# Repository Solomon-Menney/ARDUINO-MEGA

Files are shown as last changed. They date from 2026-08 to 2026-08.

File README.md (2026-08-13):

## 📌 Project Overview

The **Custom Arduino Mega** is an open-source hardware project developed as a custom implementation of the Arduino Mega platform.

The board is suitable for:

* Embedded systems development
* Robotics projects
* Automation and control systems
* IoT applications
* Sensor interfacing
* Motor control
* Electronics prototyping
* Academic and engineering projects

---

## ✨ Features

* ATmega2560 microcontroller
* Arduino Mega-compatible architecture
* Digital I/O pins
* Analog input pins
* PWM outputs
* UART serial communication
* SPI communication
* I²C communication
* USB programming/communication interface
* External power input
* On-board voltage regulation
* Reset circuit
* ICSP programming interface
* Power and status indicators
* Standard Arduino-style headers

---

## 🔧 Main Specifications

| Parameter | Specification  |
| --- | --- |
| Microcontroller | ATmega2560 |
| Architecture | 8-bit AVR |
| Operating Voltage | 5 V |
| Digital I/O | 54 |
| PWM Outputs | 15 |
| Analog Inputs | 16 |
| UART Ports | 4 |
| Communication | UART, SPI, I²C |
| Clock Frequency | 16 MHz |
| Programming | USB / ICSP |
| PCB Design Software | KiCad |
| Board Type | Custom PCB |

---

## 🧠 Microcontroller

The main controller used on the board is the **ATmega2560**.

The microcontroller provides a large number of digital and analog I/O pins, making the board suitable for projects that require more pins than a standard Arduino Uno.

### ATmega2560 Functions

* Digital input/output
* Analog-to-digital conversion
* PWM generation
* Hardware timers
* UART communication
* SPI communication
* I²C communication
* External interrupts
* Flash, SRAM and EEPROM memory

---

## 🔌 Communication Interfaces

The board supports several communication protocols.

### UART

The ATmega2560 provides four hardware serial interfaces:

* Serial0
* Serial1
* Serial2
* Serial3

These can be used to communicate with:

* GPS modules
* GSM modules
* Bluetooth modules
* Other microcontrollers
* Computers

### I²C

I²C can be used to connect devices such as:

* Sensors
* LCD displays
* RTC modules
* EEPROMs
* I/O expanders

### SPI

SPI can be used for high-speed communication with:

* SD cards
* Displays
* Sensors
* Flash memory
* Other SPI devices

---

## ⚡ Power Supply

The board contains a dedicated power section for supplying the required voltage to the microcontroller and other circuits.

Possible power sources include:

* USB
* External DC input

The power section includes:

* Voltage regulation
* Power filtering
* Decoupling capacitors
* Reverse-polarity protection *(if implemented)*
* Power indicator LED

> **Note:** Verify the exact input-voltage range of your implemented power circuit before connecting an external supply.

---

## 🔄 Reset Circuit

A reset circuit is included to allow the ATmega2560 to restart and enter the bootloader/programming process.

The reset circuit consists of components such as:

* Reset push button
* Pull-up resistor
* Reset capacitor *(depending on the design)*

---

## 💻 Programming

The board can be programmed using the Arduino IDE or another compatible AVR development environment.

### Arduino IDE

1. Install the Arduino IDE.
2. Connect the board to a computer through USB.
3. Select the appropriate board configuration.
4. Select the correct COM port.
5. Upload your Arduino program.

For a Mega-compatible configuration, select:

**Tools → Board → Arduino Mega or Mega 2560**

Then select the appropriate processor option for your hardware.

## 🖥️ PCB Design

The PCB was designed using **KiCad**.

The project includes the following design files:

```text
Custom-Arduino-Mega/
│
├── README.md
│
├── Schematic/
│   └── Arduino_Mega.kicad_sch
│
├── PCB/
│   └── Arduino_Mega.kicad_pcb
│
├── Gerber/
│   └── Manufacturing_Files/
│
├── 3D/
│   └── PCB_3D_View/
│
└── Documentation/
    ├── Pinout/
    └── Images/
```

---

## 📐 Design Files

The repository contains:

* KiCad schematic
* KiCad PCB layout
* Gerber files
* Drill files
* Bill of Materials (BOM)
* Component datasheets
* Firmware/test programs
* PCB renders
* Project documentation

---

## 🧾 Bill of Materials

| Component | Description | Quantity |
| --- | --- | ---: |
| ATmega2560 | Main microcontroller | 1 |
| USB Interface | USB communication/programming | 1 |
| Voltage Regulator  | 5 V regulation | 1 |
| Crystal/Oscillator | 16 MHz clock | 1 |
| Capacitors | Power/decoupling | Several |
| Resistors | Pull-up/current limiting | Several |
| LEDs | Power/status indicators | Several |
| Push Button | Reset | 1 |
| Pin Headers | I/O connections | Several |
| Diodes | Protection | As required |

> The exact component values and part numbers are provided in the project schematic and BOM.

---

## 📷 Project Images

Add your project images here.

### Schematic

Schematic

### PCB Layout

PCB Layout

### 3D PCB View

3D PCB

This custom Arduino Mega board can be used in:

* Industrial automation
* Robotics
* Smart home systems
* IoT systems
* Solar energy systems
* Motor control
* Sensor networks
* Data acquisition
* Embedded control systems
* Engineering research and education

---

## 🛠️ Tools Used

### Hardware Design

* KiCad
* ATmega2560 datasheet
* AVR documentation

### Software

* Arduino IDE
* AVR toolchain

### Manufacturing

* PCB fabrication service
* Soldering and assembly tools

---

Documentation

Important documents are included in the `Documentation` directory.

These may include:

* Circuit schematic
* PCB layout
* Pinout diagram
* Datasheets
* BOM
* Design calculations
* Assembly information
* Testing results

---

Recommended Tests

* [ ] Visual inspection
* [ ] Check for PCB shorts
* [ ] Verify power input
* [ ] Verify regulated voltage
* [ ] Test reset circuit
* [ ] Test USB communication
* [ ] Test microcontroller programming
* [ ] Test digital I/O
* [ ] Test analog inputs
* [ ] Test UART
* [ ] Test I²C
* [ ] Test SPI

---

## 📈 Future Improvements

Possible future improvements include:

* Improved power protection
* USB-C connector
* Additional power monitoring
* Battery input
* Reverse-polarity protection
* ESD protection
* Improved PCB layout
* Additional status indicators
* More expansion connectors
* Improved thermal management

---

 Author
SOLOMON MENNEY
Electrical/Electronic Engineering Student
Accra Technical University

**Built with KiCad, AVR technology, and a passion for embedded systems.**

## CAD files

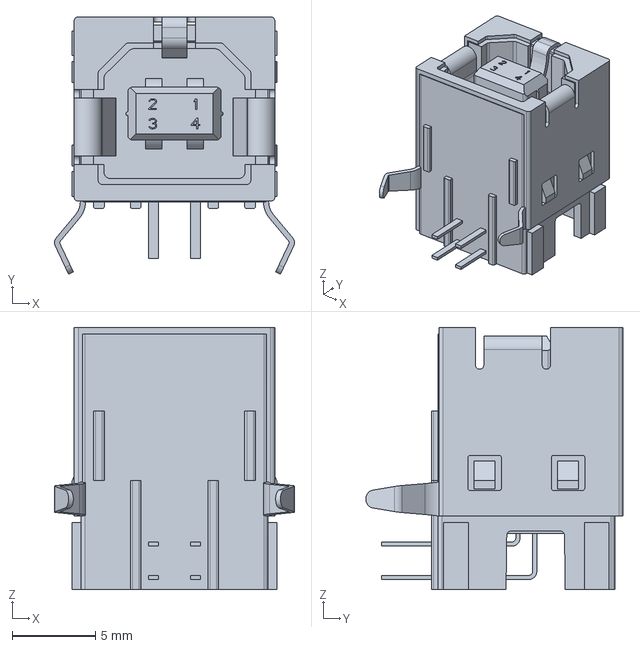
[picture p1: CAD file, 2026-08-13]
100623.stp
14.4 x 15.4 x 15.7 mm

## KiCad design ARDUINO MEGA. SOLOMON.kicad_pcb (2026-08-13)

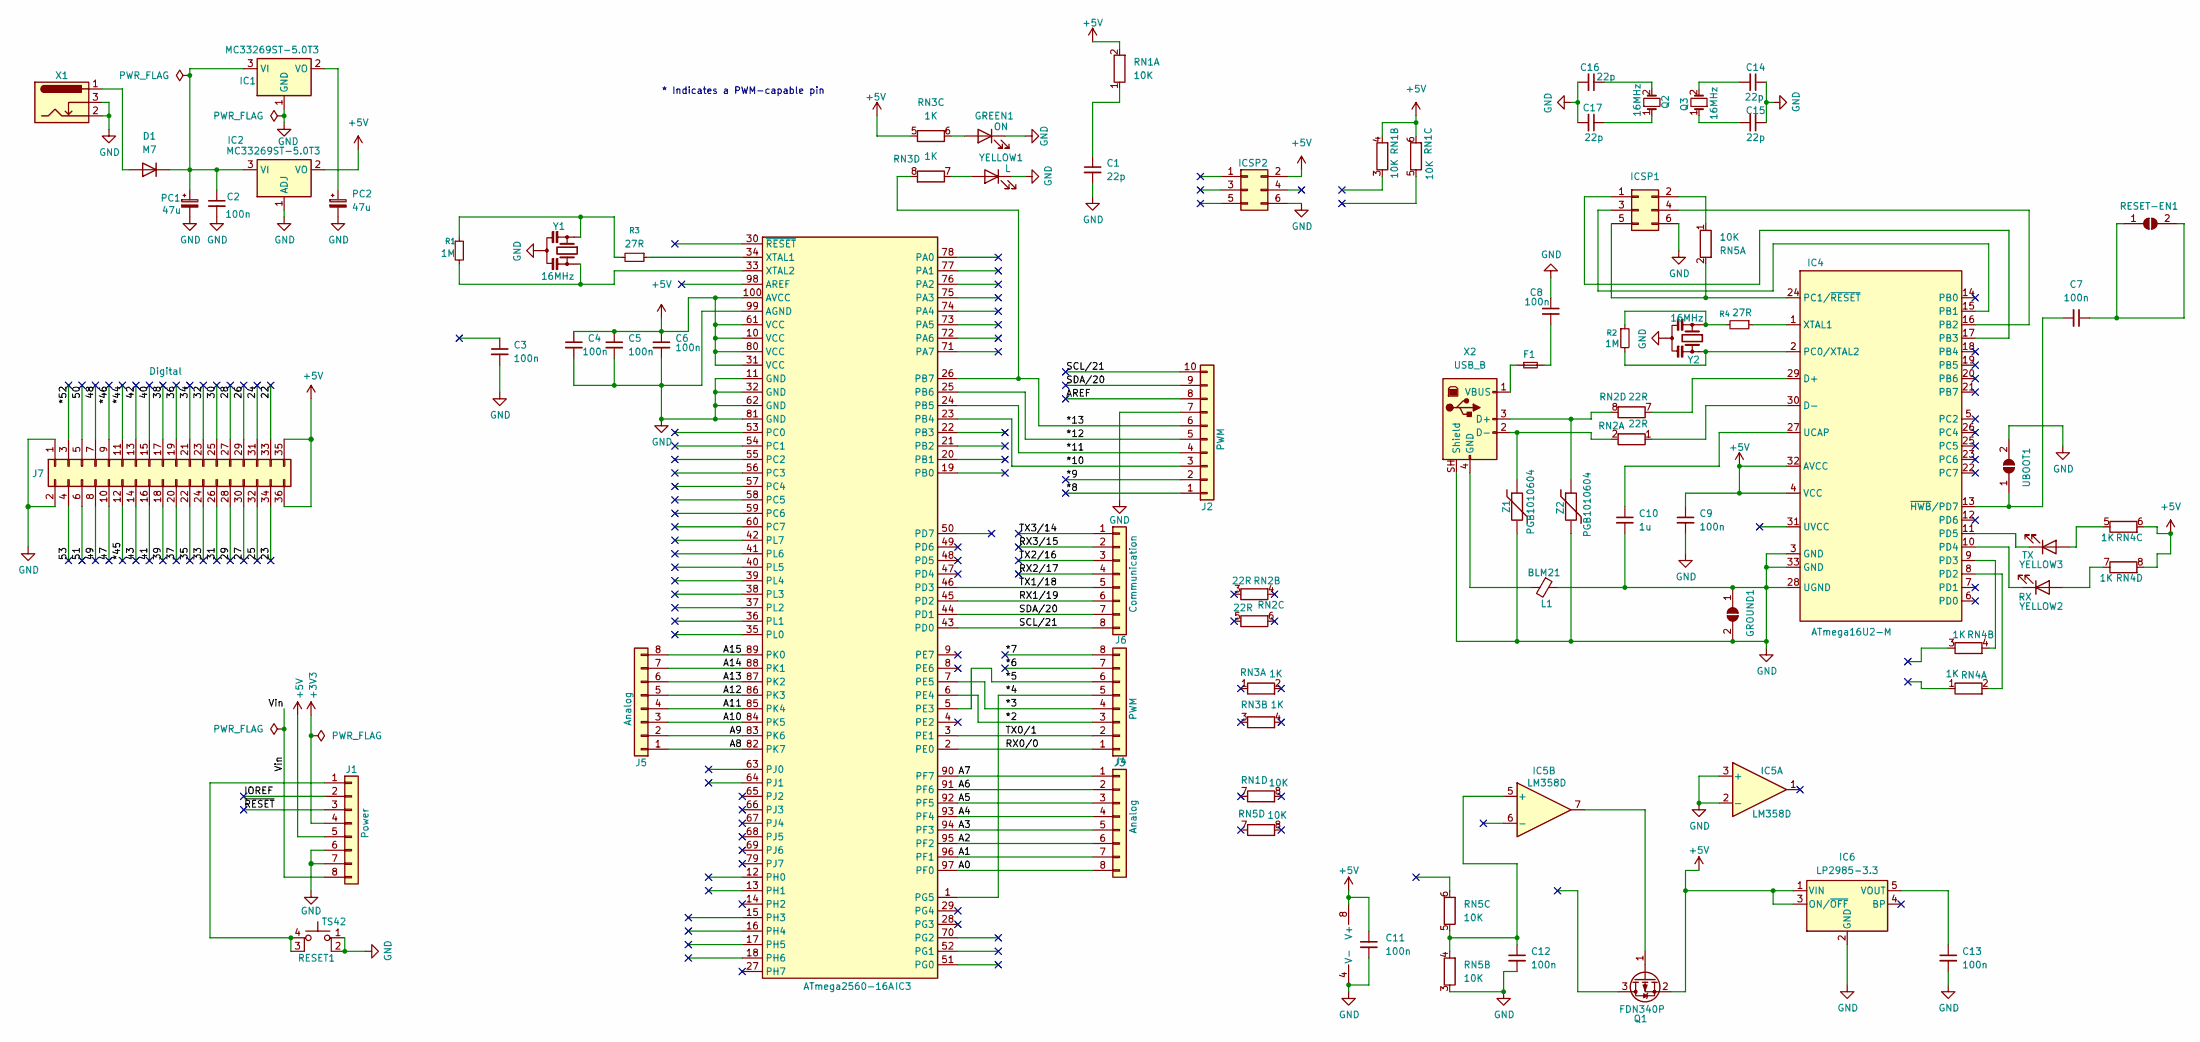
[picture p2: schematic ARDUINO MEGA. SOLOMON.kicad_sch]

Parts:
C1, C14, C15, C16, C17: 22p; C_0805_2012Metric
C2, C3, C4, C5, C6, C7, C8, C9, C11, C12, C13: 100n; C_0805_2012Metric
C10: 1u; C_0805_2012Metric
D1: M7; D_SMA
F1: 500mA; Fuse_1812_4532Metric
GREEN1: ON; LED_0805_2012Metric
GROUND1: SolderJumper_2_Open; SolderJumper-2_P1.3mm_Bridged_Pad1.0x1.5mm
IC1, IC2: MC33269ST-5.0T3; SOT-223-3_TabPin2
IC3: ATmega2560-16A; TQFP-100_14x14mm_P0.5mm
IC4: ATmega16U2-M; QFN-32-1EP_5x5mm_P0.5mm_EP3.1x3.1mm
IC5: LM358D; SOIC-8_3.9x4.9mm_P1.27mm
IC6: LP2985-3.3; SOT-23-5
ICSP1, ICSP2: Conn_02x03_Odd_Even; PinHeader_2x03_P2.54mm_Vertical
J1: Power; PinSocket_1x08_P2.54mm_Vertical
J2: PWM; PinSocket_1x10_P2.54mm_Vertical
J3, J5: Analog; PinSocket_1x08_P2.54mm_Vertical
J4: PWM; PinSocket_1x08_P2.54mm_Vertical
J6: Communication; PinSocket_1x08_P2.54mm_Vertical
J7: Digital; PinSocket_2x18_P2.54mm_Vertical
L1: BLM21; L_0805_2012Metric
PC1, PC2: 47u; CP_Elec_6.3x5.4
Q1: FDN340P; SOT-23
Q2, Q3: 16MHz; Crystal_SMD_5032-2Pin_5.0x3.2mm
R1, R2: 1M; R_0805_2012Metric
R3, R4: 27R; R_0805_2012Metric
RESET1: TS42; SW_SPST_PTS645Sx43SMTR92
RESET-EN1: SolderJumper_2_Open; SolderJumper-2_P1.3mm_Bridged_Pad1.0x1.5mm
RN1, RN5: 10K; R_Array_Convex_4x0603
RN2: 22R; R_Array_Convex_4x0603
RN3, RN4: 1K; R_Array_Convex_4x0603
UBOOT1: SolderJumper_2_Open; SolderJumper-2_P1.3mm_Bridged_Pad1.0x1.5mm
X1: Barrel_Jack_Switch; BarrelJack_Horizontal
X2: USB_B; USB_B_OST_USB-B1HSxx_Horizontal
Y1: 16MHz; Crystal_SMD_HC49-SD
Y2: 16MHz; Resonator_SMD_Murata_CSTxExxV-3Pin_3.0x1.1mm
YELLOW1: L; LED_0805_2012Metric
YELLOW2: RX; LED_0805_2012Metric
YELLOW3: TX; LED_0805_2012Metric
Z1, Z2: PGB1010604; R_0603_1608Metric

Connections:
+3V3: J1.4
+5V: C4.1, C5.1, C6.1, C9.1, C11.1, IC2.2 (VO), IC3.10 (VCC), IC3.31 (VCC), IC3.61 (VCC), IC3.80 (VCC), IC3.100 (AVCC), IC4.4 (VCC), IC4.32 (AVCC), IC5.8 (V+), IC6.1 (VIN), IC6.3 (ON/~OFF), ICSP2.2, J1.5, J7.35, J7.36, Q1.2 (S), RN1.2 (R1.2), RN1.4 (R2.2), RN1.6 (R3.2), RN3.5 (R3.1), RN4.6 (R3.2), RN4.8 (R4.2)
/22: J7.33
/23: J7.34
/24: J7.31
/25: J7.32
/26: J7.29
/27: J7.30
/28: J7.27
/29: J7.28
/30: J7.25
/31: J7.26
/32: J7.23
/33: J7.24
/34: J7.21
/35: J7.22
/36: J7.19
/37: J7.20
/38: J7.17
/39: J7.18
/40: J7.15
/41: J7.16
/42: J7.13
/43: J7.14
/47: J7.10
/48: J7.7
/49: J7.8
/50: J7.5
/51: J7.6
/53: J7.4
/*2: IC3.6 (PE4), J4.3
/*3: IC3.7 (PE5), J4.4
/*4: IC3.1 (PG5), J4.5
/*5: IC3.5 (PE3), J4.6
/*6: J4.7
/*7: J4.8
/*8: J2.1
/*9: J2.2
/*10: IC3.23 (PB4), J2.3
/*11: IC3.24 (PB5), J2.4
/*12: IC3.25 (PB6), J2.5
/*13: IC3.26 (PB7), J2.6, RN3.8 (R4.2)
/*44: J7.11
/*45: J7.12
/*46: J7.9
/*52: J7.3
/A0: IC3.97 (PF0), J3.8
/A1: IC3.96 (PF1), J3.7
/A2: IC3.95 (PF2), J3.6
/A3: IC3.94 (PF3), J3.5
/A4: IC3.93 (PF4), J3.4
/A5: IC3.92 (PF5), J3.3
/A6: IC3.91 (PF6), J3.2
/A7: IC3.90 (PF7), J3.1
/A8: IC3.82 (PK7), J5.1
/A9: IC3.83 (PK6), J5.2
/A10: IC3.84 (PK5), J5.3
/A11: IC3.85 (PK4), J5.4
/A12: IC3.86 (PK3), J5.5
/A13: IC3.87 (PK2), J5.6
/A14: IC3.88 (PK1), J5.7
/A15: IC3.89 (PK0), J5.8
/AREF: J2.8
/IOREF: J1.2
/RX0/0: IC3.2 (PE0), J4.1
/RX1/19: IC3.45 (PD2), J6.6
/RX2/17: J6.4
/RX3/15: J6.2
/SCL/21: IC3.43 (PD0), J2.10, J6.8
/SDA/20: IC3.44 (PD1), J2.9, J6.7
/TX0/1: IC3.3 (PE1), J4.2
/TX1/18: IC3.46 (PD3), J6.5
/TX2/16: J6.3
/TX3/14: J6.1
/Vin: J1.8
/~RESET: J1.3
GND: C1.2, C2.2, C3.2, C4.2, C5.2, C6.2, C8.1, C9.2, C10.2, C11.2, C12.2, C13.2, C14.1, C15.1, C16.2, C17.2, GREEN1.1 (K), GROUND1.1 (A), GROUND1.2 (B), IC1.1 (GND), IC2.1 (ADJ), IC3.11 (GND), IC3.32 (GND), IC3.62 (GND), IC3.81 (GND), IC3.99 (AGND), IC4.3 (GND), IC4.28 (UGND), IC4.33 (GND), IC5.2 (-), IC5.3 (+), IC5.4 (V-), IC6.2 (GND), ICSP1.6, ICSP2.6, J1.6, J1.7, J2.7, J7.1, J7.2, L1.1, PC1.2, PC2.2, RESET1.1, RESET1.2, RN5.3 (R2.1), UBOOT1.2 (B), X1.2, X1.3, X2.SH (Shield), Y1.2, Y2.2, YELLOW1.1 (K), Z1.2, Z2.2
unnamed: C8.2, F1.2
unnamed: C14.2, Q3.2
unnamed: C15.2, Q3.1
unnamed: C16.1, Q2.2
unnamed: C17.1, Q2.1
unnamed: D1.2 (A), X1.1
unnamed: C2.1, D1.1 (K), IC1.3 (VI), IC2.3 (VI), PC1.1
unnamed: GREEN1.2 (A), RN3.6 (R3.2)
unnamed: IC1.2 (VO), PC2.1
unnamed: IC3.34 (XTAL1), R3.1
unnamed: IC3.33 (XTAL2), R1.2, Y1.3
unnamed: IC4.29 (D+), RN2.7 (R4.1)
unnamed: IC4.30 (D-), RN2.1 (R1.1)
unnamed: IC4.15 (PB1), ICSP1.3
unnamed: IC4.16 (PB2), ICSP1.4
unnamed: IC4.17 (PB3), ICSP1.1
unnamed: IC4.2 (PC0/XTAL2), R2.2, Y2.3
unnamed: IC4.24 (PC1/~RESET), ICSP1.5, RN5.2 (R1.2)
unnamed: IC4.8 (PD2), RN4.2 (R1.2)
unnamed: IC4.9 (PD3), RN4.4 (R2.2)
unnamed: IC4.10 (PD4), YELLOW2.1 (K)
unnamed: IC4.11 (PD5), YELLOW3.1 (K)
unnamed: C10.1, IC4.27 (UCAP)
unnamed: IC4.1 (XTAL1), R4.1
unnamed: C7.2, IC4.13 (~HWB/PD7), UBOOT1.1 (A)
unnamed: C12.1, IC5.5 (+), RN5.4 (R2.2), RN5.5 (R3.1)
unnamed: C13.1, IC6.5 (VOUT)
unnamed: ICSP1.2, RN5.1 (R1.1)
unnamed: J1.1, RESET1.3 (K), RESET1.4 (A)
unnamed: IC5.7, Q1.1 (G)
unnamed: R1.1, R3.2, Y1.1
unnamed: R2.1, R4.2, Y2.1
unnamed: C7.1, RESET-EN1.1 (A), RESET-EN1.2 (B)
unnamed: C1.1, RN1.1 (R1.1)
unnamed: RN2.2 (R1.2), X2.2 (D-), Z1.1
unnamed: RN2.8 (R4.2), X2.3 (D+), Z2.1
unnamed: RN3.7 (R4.1), YELLOW1.2 (A)
unnamed: RN4.5 (R3.1), YELLOW3.2 (A)
unnamed: RN4.7 (R4.1), YELLOW2.2 (A)
unnamed: L1.2, X2.4 (GND)
unnamed: F1.1, X2.1 (VBUS)

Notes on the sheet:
* Indicates a PWM-capable pin

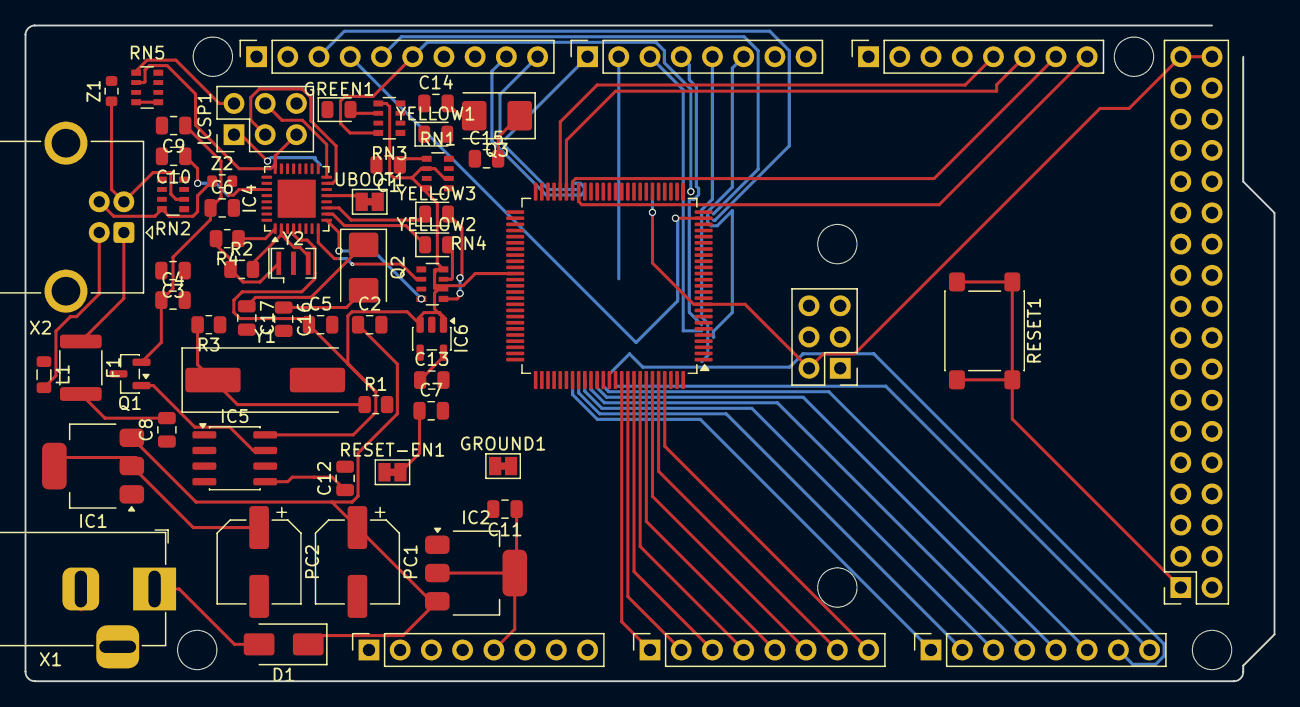
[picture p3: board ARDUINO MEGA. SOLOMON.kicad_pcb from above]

Board: 2 copper layers, 101.6 x 53.3 mm, 69 parts (0 on the bottom side), 72 nets.

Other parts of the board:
MH1, MH2, MH3, MH4, MH5, MH6: MountingHole_3.2mm
